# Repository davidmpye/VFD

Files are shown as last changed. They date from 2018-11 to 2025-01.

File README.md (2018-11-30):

This repository contains a design for an IV-11 based Vacuum Fluorescent Display (VFD) display unit.

Key points of the design:

* Support for 8 tubes (can install only 6 if you want the traditional 2-2-2 clock display)
* Can daisy chain boards to make longer displays
* Wifi capable (MQTT etc? - firmware doesn't yet enable this)
* Runs off a 5V 2A supply (USB B socket)
* Four buttons for setting time/other functions

Parts count/prices kept down by using 'generic' ebay modules to provide:

* DS3231 Real Time Clock (battery backed)
* Boost converter module to provide the ~25VDC to power the VFD
* Buck converter module to provide 1.5v to heat the cathodes
* Wemos D1 Mini board to provide the brains
* 5mm encapsulated addressable RGB LEDs to provide the colour effects.

Finished clock

Please see the project wiki for more details.

https://github.com/davidmpye/VFD/wiki

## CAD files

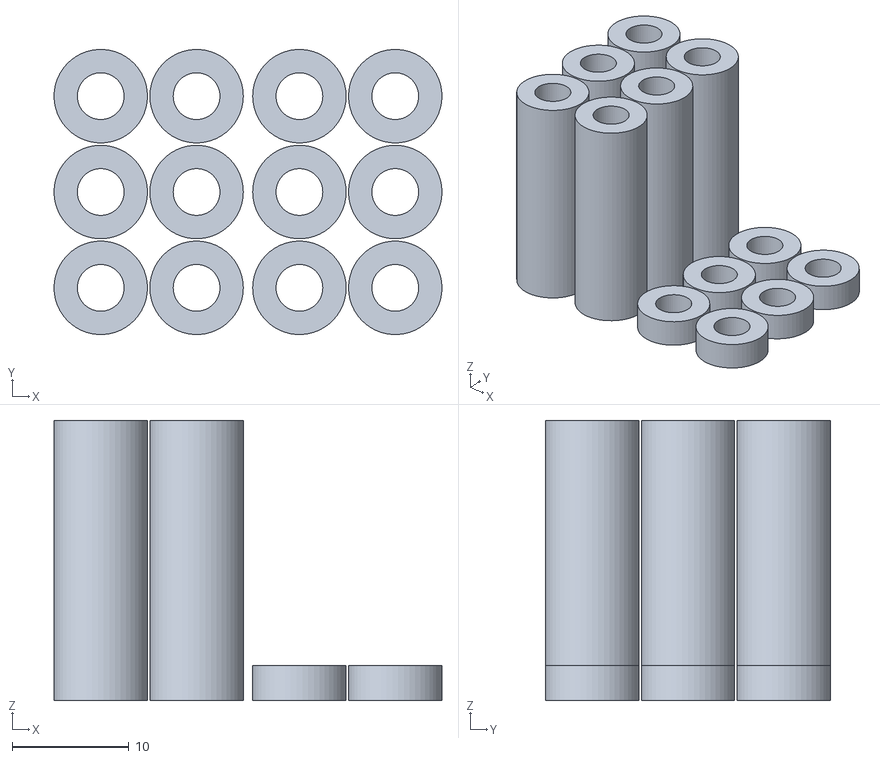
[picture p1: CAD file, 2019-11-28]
IV11/Spacers.stl
33.2 x 24.4 x 24.0

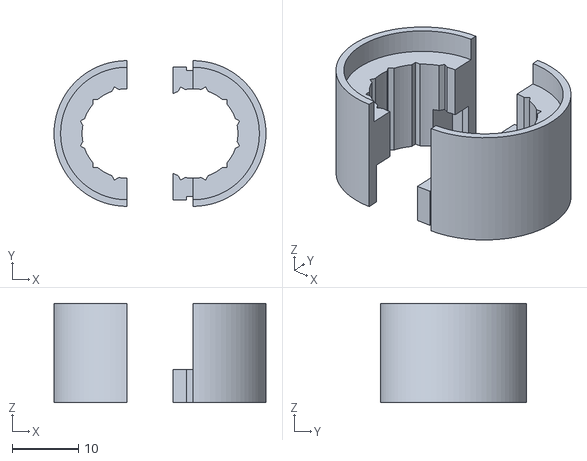
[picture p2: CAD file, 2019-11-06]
IV11/IV11Base.stl
32.0 x 22.0 x 15.0

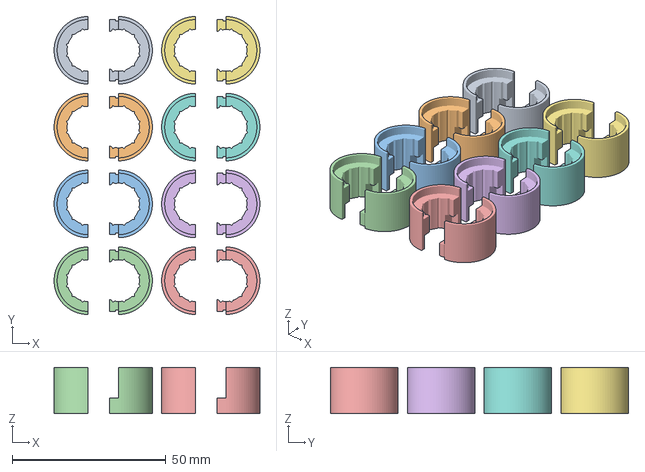
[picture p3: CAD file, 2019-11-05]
IV11/IV11basesx8.3mf
67.0 x 97.0 x 15.0 mm

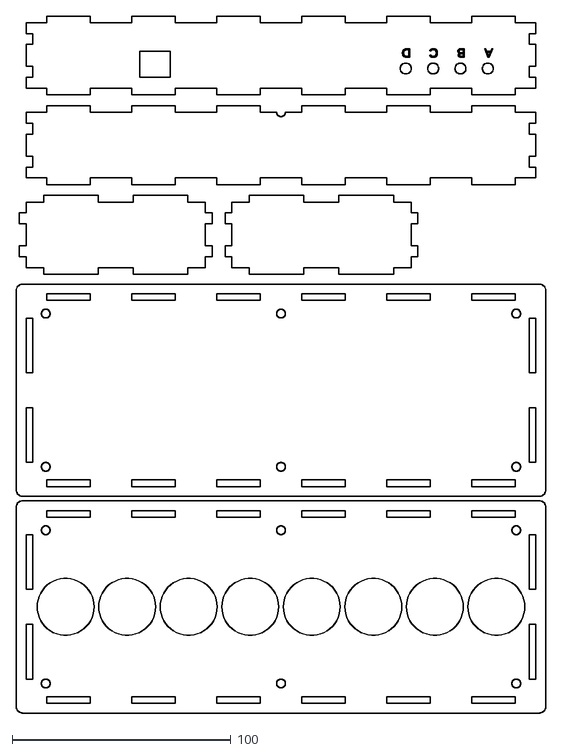
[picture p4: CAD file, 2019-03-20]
IV11/clock_case.dxf
242.0 x 318.5

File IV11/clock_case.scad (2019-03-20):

$fn=50;

material_thickness = 3; //in mm

outer_x = 225 + 2  + material_thickness * 4;
outer_y = 80 + 2  + material_thickness * 4;
outer_z = 30 + 2*material_thickness; //30 inside


x_edge_notches = 6;		//Number of notches along the X side of the box
x_edge_notch_len = 20;

y_edge_notches = 2;		//Number of notches along the Y side of box
y_edge_notch_len = 25;

z_edge_notches = 2;    
z_edge_notch_len = 5;

z_edge_gap_between_notches = ( ((outer_z-2*material_thickness) - (z_edge_notch_len * z_edge_notches)) / z_edge_notches);
//space INSIDE box is as follows:

//X is outer_x  minus 4x material thickness
//Y is outer_y minux 4xmaterial thickness
//Z is outer_z minus 2x material_thickness



long_edge_gap_between_notches = (outer_y - (material_thickness*4) -  (y_edge_notch_len * y_edge_notches)) / y_edge_notches  ;
short_edge_gap_between_notches = (outer_x - (material_thickness*2) -  (x_edge_notch_len * x_edge_notches)) / x_edge_notches;


module top_face() {
radius = 3;
   difference() {
		//square([outer_x,outer_y]);
		hull() {

    		translate([(radius/2), (radius/2), 0])
    		circle(r=radius);

   		translate([(outer_x)-(radius/2), (radius/2), 0])
    		circle(r=radius);

    		translate([(radius/2), (outer_y)-(radius/2), 0])
    		circle(r=radius);

   		 translate([(outer_x)-(radius/2), (outer_y)-(radius/2), 0])
   		 circle(r=radius);		
		}


		for (a=[0:y_edge_notches-1]) {
			translate([material_thickness,  material_thickness*2 + ((long_edge_gap_between_notches * a ) + (a * y_edge_notch_len) +  (0.5 * long_edge_gap_between_notches)) ,0]  ) square([material_thickness,y_edge_notch_len]);
   	}
	
		for (a=[0:y_edge_notches-1]) {
			translate([outer_x - ( material_thickness*2),  (2*material_thickness + (long_edge_gap_between_notches * a ) + (a * y_edge_notch_len) +  (0.5 * long_edge_gap_between_notches)) ,0]  ) square([material_thickness,y_edge_notch_len]);
		}

	for (a=[0:x_edge_notches-1]) {
			
translate([material_thickness + x_edge_notch_len + 0.5*short_edge_gap_between_notches + x_edge_notch_len*a + a*short_edge_gap_between_notches,material_thickness,0]) rotate([0,0,90]) square([material_thickness, x_edge_notch_len]);
		}

	for (a=[0:x_edge_notches-1]) {
			
translate([material_thickness + x_edge_notch_len + 0.5*short_edge_gap_between_notches + x_edge_notch_len*a + a*short_edge_gap_between_notches,outer_y - (material_thickness*2),0]) rotate([0,0,90]) square([material_thickness, x_edge_notch_len]);
		}

	}
}

module long_side_face() {
	union() {
		square([outer_y-(material_thickness*4), outer_z - (material_thickness*2)]);
		//lugs for the long edge
		for (a=[0:y_edge_notches-1]) {
			translate([((long_edge_gap_between_notches * a ) + (a * y_edge_notch_len) +  (0.5 * long_edge_gap_between_notches)),-material_thickness,0]) square([y_edge_notch_len, outer_z]);
		}

			}
		for (a=[0:z_edge_notches - 1 ]) {
			translate([-material_thickness,(0.5 * z_edge_gap_between_notches) + (z_edge_notch_len * a) + (a*z_edge_gap_between_notches),0]) square([material_thickness, z_edge_notch_len]);

			translate([outer_y - 4*material_thickness,(0.5 * z_edge_gap_between_notches) + (z_edge_notch_len * a) + (a*z_edge_gap_between_notches),0]) square([material_thickness, z_edge_notch_len]);
		}



}

module short_side_face() {
	difference() {
		union() {
			square([outer_x - (2*material_thickness), outer_z-(2*material_thickness)]);
			//lugs
			for (a=[0:x_edge_notches-1]) {
				translate([0.5*short_edge_gap_between_notches + x_edge_notch_len*a + a*short_edge_gap_between_notches,-material_thickness,0]) square([x_edge_notch_len,outer_z]);
			}
		}

		//Z notches
		for (a=[0:z_edge_notches - 1 ]) {
			translate([0,(0.5 * z_edge_gap_between_notches) + (z_edge_notch_len * a) + (a*z_edge_gap_between_notches),0]) square([material_thickness, z_edge_notch_len]);

			translate([outer_x - 3*material_thickness,(0.5 * z_edge_gap_between_notches) + (z_edge_notch_len * a) + (a*z_edge_gap_between_notches),0]) square([material_thickness, z_edge_notch_len]);
		}
	}
}

vfd_tube_dia = 24+2;

difference() {
	top_face();
    translate([2*material_thickness + 1, 2*material_thickness + 1, 0]) {
        for (a=[0:7]) {
            //VFD holes
            translate([14.0625 + (28.125 * a), 40,0]) circle(d=vfd_tube_dia);     
        }
        //the 6 M4 mounting holes.
        //the 6 M4 mounting holes.
        translate([5,5,0]) circle(d=4);
        translate([5,75,0]) circle(d=4);
        translate([225 - 5,5,0]) circle(d=4);
        translate([225 - 5,75,0]) circle(d=4);
        translate([225/2,5,0]) circle(d=4);
        translate([225/2,75,0]) circle(d=4);
    
       //LDR hole if wanted top mounted one
     //  translate([225/2 + 12,5,0]) circle(d=5);
         
       }    
}



translate([0,outer_y + 5,0]) difference() {
	top_face();
      translate([2*material_thickness + 1, 2*material_thickness + 1, 0]) {
       //the 6 M4 mounting holes.
        translate([5,5,0]) circle(d=4);
        translate([5,75,0]) circle(d=4);
        translate([225 - 5,5,0]) circle(d=4);
        translate([225 - 5,75,0]) circle(d=4);
        translate([225/2,5,0]) circle(d=4);
        translate([225/2,75,0]) circle(d=4);
      }


}


translate([material_thickness,outer_y*2 + 5 + material_thickness*2 + 3,0]) rotate(0,0,0) difference() {
    long_side_face();        
}

translate([material_thickness + outer_y,outer_y*2 + 5 + material_thickness*2 + 3,0]) rotate(0,0,0) long_side_face();

translate([material_thickness, outer_y*2 + outer_z + 10 + material_thickness*2 + 3 ,0]) difference() {
    short_side_face() ;
    //This takes a small nick out of the front face to make it easier to mount the LDR forward facing into room.
    translate([outer_x/2 - material_thickness, outer_z - material_thickness - 3, 0]) circle(r=2);
}
    

translate([material_thickness, outer_y*2 + outer_z *2 + 15 + material_thickness*2 + 3 ,0]) difference() {
short_side_face();
      translate([2*material_thickness + 1, 2*material_thickness, -1]) {
       
       //the four switch holes.
       //m4
       translate([222.5 - 18.5 - 12.5*0 ,3, 0]) circle(d=5);
       translate([222.5 - 18.5 - 12.5*1 ,3, 0]) circle(d=5);
       translate([222.5 - 18.5 - 12.5*2 ,3, 0]) circle(d=5);
       translate([222.5 - 18.5 - 12.5*3 ,3 ,0]) circle(d=5);
          
       //Labels for the switch button holes   
       translate([222.5 - 18.5 - 12.5*0 +2.25 ,12, 0]) rotate([0,0,180]) text(size=4, text="A");
       translate([222.5 - 18.5 - 12.5*1 +2.25 ,12, 0]) rotate([0,0,180]) text(size=4, text="B");
       translate([222.5 - 18.5 - 12.5*2 +2.25 ,12, 0]) rotate([0,0,180]) text(size=4, text="C");
       translate([222.5 - 18.5 - 12.5*3 +2.25 ,12, 0]) rotate([0,0,180]) text(size=4, text="D");
      
      //The USB power connector.
      //14wide, 12 high.
      translate([45,-1,0]) square([14,12]);   
          
          
      }
      
}

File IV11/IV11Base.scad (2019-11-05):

//Uses Nophead's polyhole.
module polyhole(h, d) {
    n = max(round(2 * d),3);
    rotate([0,0,180])
        cylinder(h = h, r = (d / 2) / cos (180 / n), $fn = n);
}

$fn=80;
total_height = 15;
neopixel_width = 8;
tube_dia = 20;
wall_thickness = 1;
base_thickness = 12;
num_pins = 12;
pin_diameter = 12;
pin_hole_dia = 1.8;

//Half with lugs.
union() {
difference() {
  cylinder(r=(tube_dia/2) + wall_thickness, h = total_height); 
  translate([0,0,base_thickness]) cylinder(r=tube_dia/2, h = 100);  
  translate([-0.01,0,0]) cylinder(d=13.5, h=100); 
    
  //translate([-neopixel_width/2,-neopixel_width/2,-0.1]) cube([neopixel_width, neopixel_width,100]);
  for (i=[0:num_pins-1]) rotate([0,0,(360/num_pins/2) + 360/num_pins * i]) translate([pin_diameter/2,0,-0.1]) polyhole(100, pin_hole_dia);
      
  
  //chop it in half.
 translate([0,-25,0]) cube([50,50,50]);

 translate([-3,-10,0]) cube([5,20,5.4]);
}
# translate([-1,-10,0]) cube([1,0.5,5.4]);
# translate([-1,9.5,0]) cube([1,0.5,5.4]);

}

//Half without lugs!
translate([10,0,0]) rotate([0,0,180]) difference() {
  cylinder(r=(tube_dia/2) + wall_thickness, h = total_height); 
  translate([0,0,base_thickness]) cylinder(r=tube_dia/2, h = 100);  
  translate([-0.01,0,0]) cylinder(d=13.5, h=100); 
    
  //translate([-neopixel_width/2,-neopixel_width/2,-0.1]) cube([neopixel_width, neopixel_width,100]);
  for (i=[0:num_pins-1]) rotate([0,0,(360/num_pins/2) + 360/num_pins * i]) translate([pin_diameter/2,0,-0.1]) polyhole(100, pin_hole_dia);
      
    difference() {
        translate([0,-25,0]) cube([50,50,50]);
        translate([-2,-10,0]) cube([5,20,5]);
        
        
    }
        # translate([0,-10,0]) cube([1,0.5,5]);
        # translate([0,9.5,0]) cube([1,0.5,5]);


}

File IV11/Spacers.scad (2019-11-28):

$fn = 50;

module spacer(height) {
difference() {
    cylinder(d=8, h=height);
    translate([0,0,-0.1]) cylinder(d=4, h=height+1);


}}



for (i = [0:2]) {
    for (j = [0:1]) {
    translate([j*8.2,  i*8.2, 0]) spacer(24);
}
}


translate([17,0,0]) for (i = [0:2]) {
    for (j = [0:1]) {
    translate([j*8.2,  i*8.2, 0]) spacer(3);
}
}

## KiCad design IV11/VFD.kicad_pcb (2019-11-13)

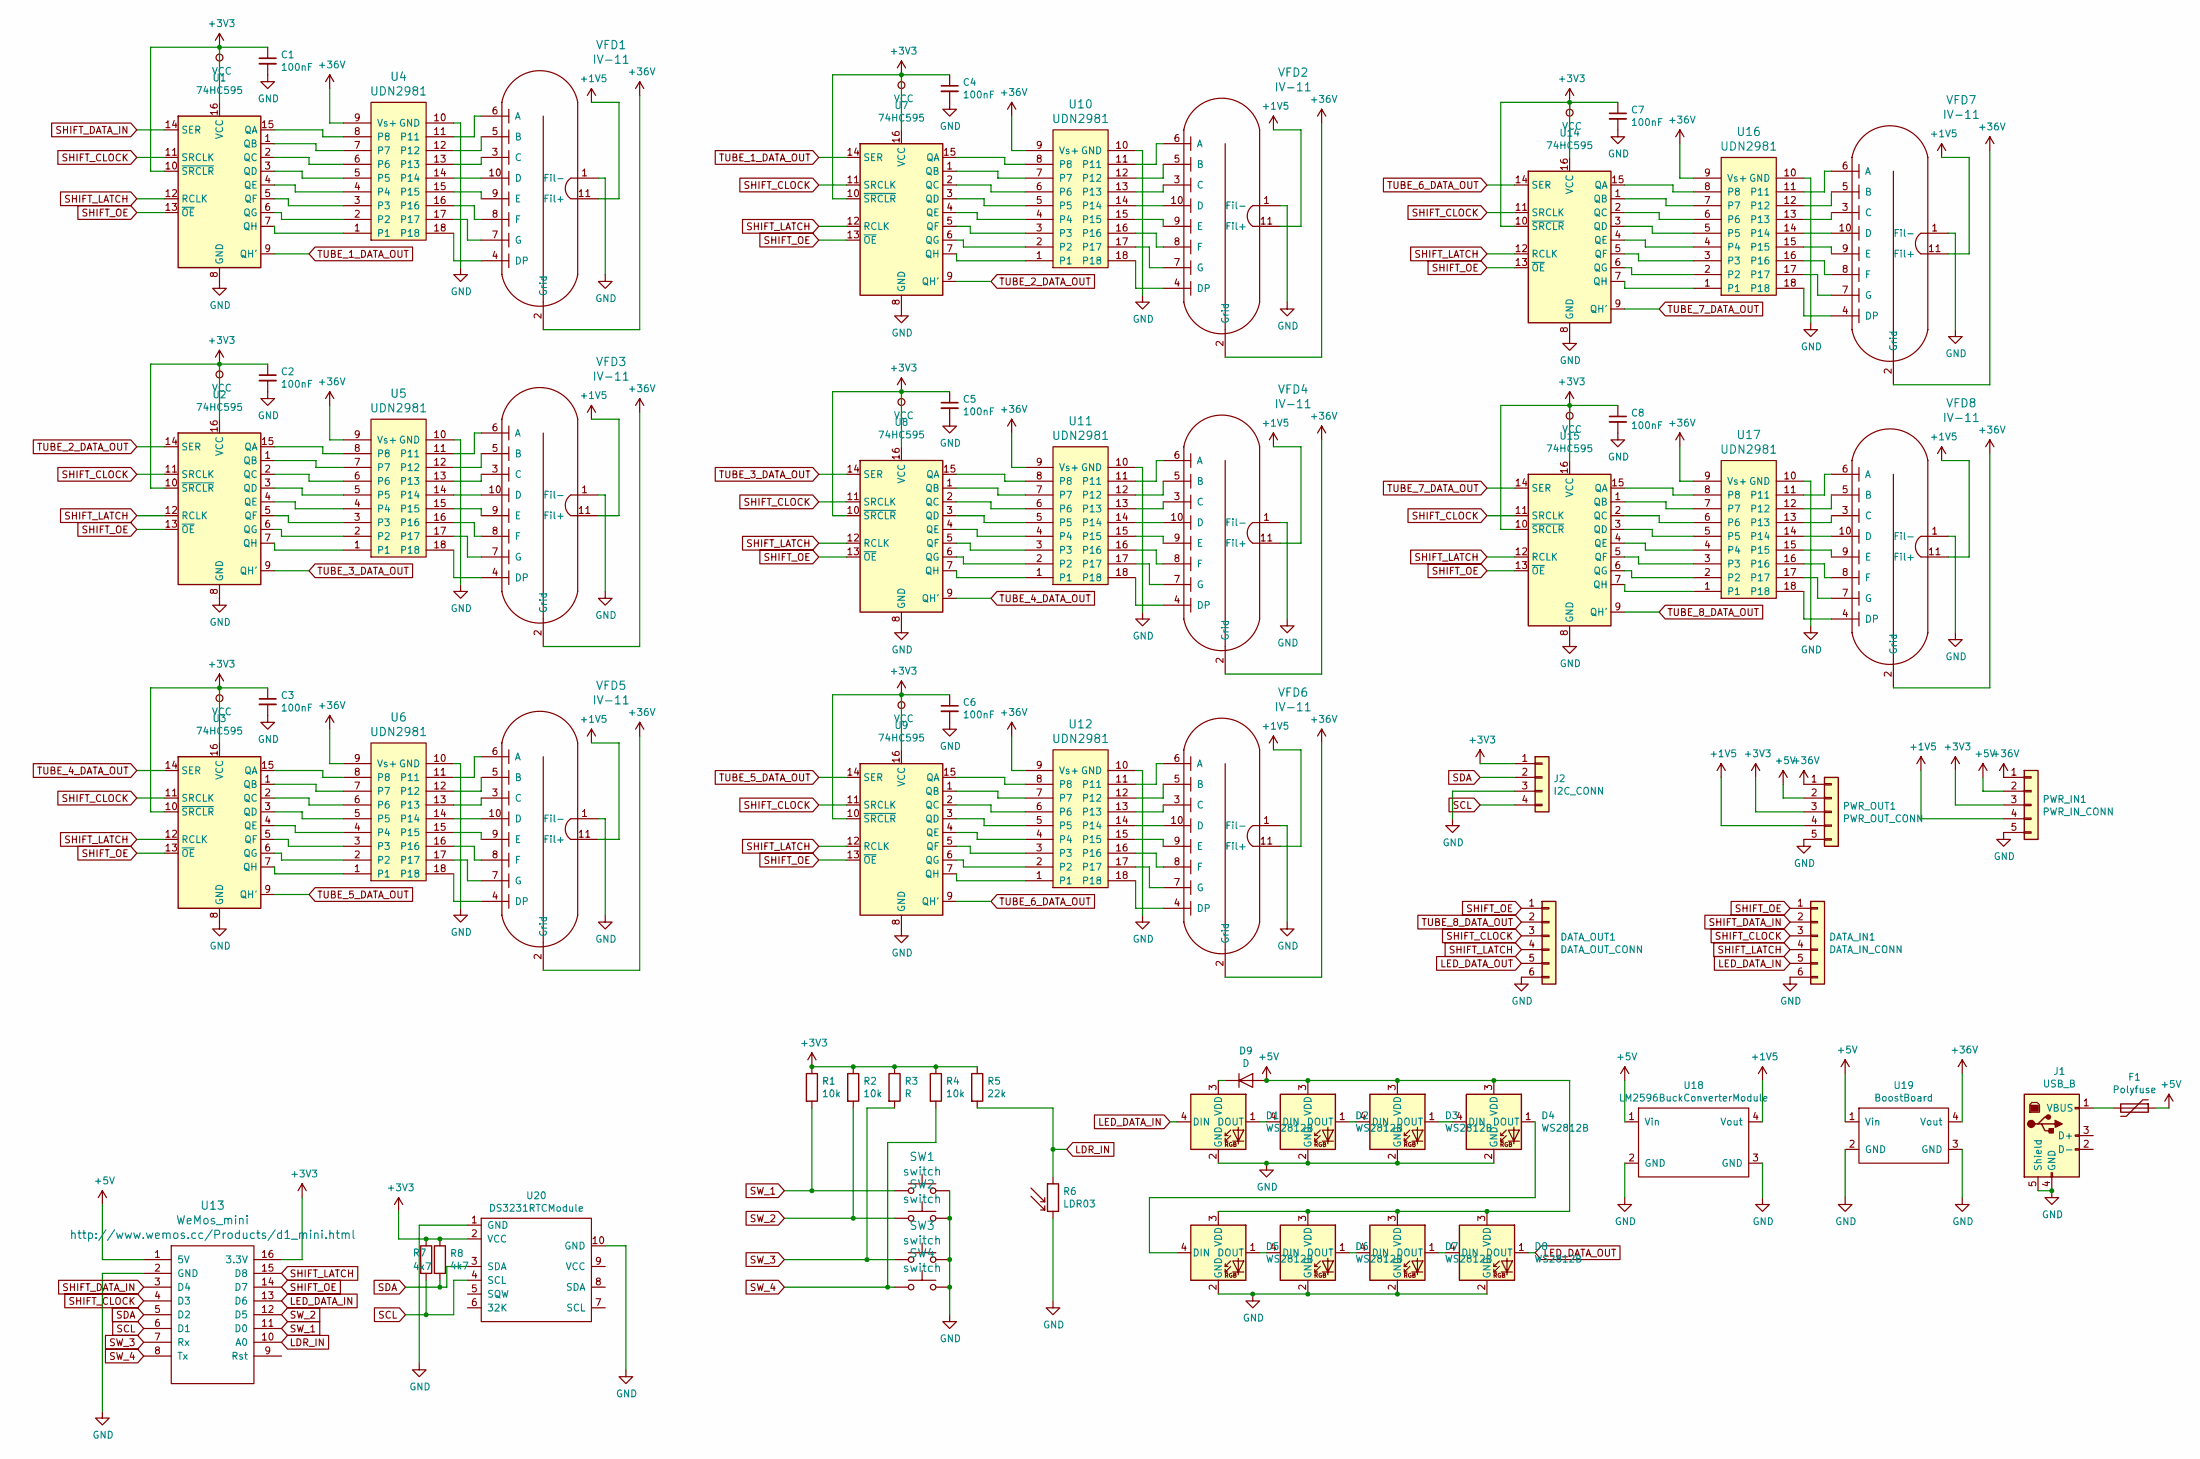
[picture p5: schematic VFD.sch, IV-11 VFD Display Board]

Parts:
C1, C2, C3, C4, C5, C6, C7, C8: 100nF; C_Disc_D7.0mm_W2.5mm_P5.00mm
D1, D2, D3, D4, D5, D6, D7, D8: WS2812B; LED_D5.0mm-4-Wide
D9: D; D_DO-35_SOD27_P7.62mm_Horizontal
DATA_IN1: DATA_IN_CONN; PinSocket_1x06_P2.54mm_Horizontal
DATA_OUT1: DATA_OUT_CONN; PinHeader_1x06_P2.54mm_Horizontal
F1: Polyfuse; R_Axial_DIN0309_L9.0mm_D3.2mm_P15.24mm_Horizontal
J1: USB_B; USB_B_OST_USB-B1HSxx_Horizontal
J2: I2C_CONN; PinHeader_1x04_P2.54mm_Horizontal
PWR_IN1: PWR_IN_CONN; PinSocket_1x05_P2.54mm_Horizontal
PWR_OUT1: PWR_OUT_CONN; PinHeader_1x05_P2.54mm_Horizontal
R1, R2, R4: 10k; R_Axial_DIN0411_L9.9mm_D3.6mm_P12.70mm_Horizontal
R3: R; R_Axial_DIN0411_L9.9mm_D3.6mm_P12.70mm_Horizontal
R5: 22k; R_Axial_DIN0411_L9.9mm_D3.6mm_P12.70mm_Horizontal
R6: LDR03; R_LDR_10x8.5mm_P7.6mm_Vertical
R7, R8: 4k7; R_Axial_DIN0411_L9.9mm_D3.6mm_P12.70mm_Horizontal
SW1, SW2, SW3, SW4: switch; SW_Tactile_SKHH_Angled
U1, U2, U3, U7, U8, U9, U14, U15: 74HC595; DIP-16_W7.62mm_Socket_LongPads
U4, U5, U6, U10, U11, U12, U16, U17: UDN2981; DIP-18_W7.62mm_Socket_LongPads
U13: WeMos_mini; D1_mini_board
U18: LM2596BuckConverterModule
U19: BoostBoard; MT3608BoostConverterModule
U20: DS3231RTCModule; DS3121RTCModule
VFD1, VFD2, VFD3, VFD4, VFD5, VFD6, VFD7, VFD8: IV-11

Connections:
+1V5: PWR_IN1.4, PWR_OUT1.4, U18.4 (Vout), VFD1.11 (Fil+), VFD2.11 (Fil+), VFD3.11 (Fil+), VFD4.11 (Fil+), VFD5.11 (Fil+), VFD6.11 (Fil+), VFD7.11 (Fil+), VFD8.11 (Fil+)
+3V3: C1.1, C2.1, C3.1, C4.1, C5.1, C6.1, C7.1, C8.1, J2.1, PWR_IN1.3, PWR_OUT1.3, R1.1, R2.1, R3.1, R4.1, R5.1, R7.1, R8.1, U1.10 (~SRCLR), U1.16 (VCC), U2.10 (~SRCLR), U2.16 (VCC), U3.10 (~SRCLR), U3.16 (VCC), U7.10 (~SRCLR), U7.16 (VCC), U8.10 (~SRCLR), U8.16 (VCC), U9.10 (~SRCLR), U9.16 (VCC), U13.16 (3.3V), U14.10 (~SRCLR), U14.16 (VCC), U15.10 (~SRCLR), U15.16 (VCC), U20.2 (VCC)
+5V: D2.3 (VDD), D3.3 (VDD), D4.3 (VDD), D5.3 (VDD), D6.3 (VDD), D7.3 (VDD), D8.3 (VDD), D9.2 (A), F1.1, PWR_IN1.2, PWR_OUT1.2, U13.1 (5V), U18.1 (Vin), U19.1 (Vin)
+36V: PWR_IN1.1, PWR_OUT1.1, U4.9 (Vs+), U5.9 (Vs+), U6.9 (Vs+), U10.9 (Vs+), U11.9 (Vs+), U12.9 (Vs+), U16.9 (Vs+), U17.9 (Vs+), U19.4 (Vout), VFD1.2 (Grid), VFD2.2 (Grid), VFD3.2 (Grid), VFD4.2 (Grid), VFD5.2 (Grid), VFD6.2 (Grid), VFD7.2 (Grid), VFD8.2 (Grid)
GND: C1.2, C2.2, C3.2, C4.2, C5.2, C6.2, C7.2, C8.2, D1.2 (GND), D2.2 (GND), D3.2 (GND), D4.2 (GND), D5.2 (GND), D6.2 (GND), D7.2 (GND), D8.2 (GND), DATA_IN1.6, DATA_OUT1.6, J1.4 (GND), J1.5 (Shield), J2.3, PWR_IN1.5, PWR_OUT1.5, R6.2, SW1.2, SW2.2, SW3.2, SW4.2, U1.8 (GND), U2.8 (GND), U3.8 (GND), U4.10 (GND), U5.10 (GND), U6.10 (GND), U7.8 (GND), U8.8 (GND), U9.8 (GND), U10.10 (GND), U11.10 (GND), U12.10 (GND), U13.2 (GND), U14.8 (GND), U15.8 (GND), U16.10 (GND), U17.10 (GND), U18.2 (GND), U18.3 (GND), U19.2 (GND), U19.3 (GND), U20.1 (GND), U20.10 (GND), VFD1.1 (Fil-), VFD2.1 (Fil-), VFD3.1 (Fil-), VFD4.1 (Fil-), VFD5.1 (Fil-), VFD6.1 (Fil-), VFD7.1 (Fil-), VFD8.1 (Fil-)
LDR_IN: R5.2, R6.1, U13.10 (A0)
LED_DATA_IN: D1.4 (DIN), DATA_IN1.5, U13.13 (D6)
LED_DATA_OUT: D8.1 (DOUT), DATA_OUT1.5
unnamed: D1.1 (DOUT), D2.4 (DIN)
unnamed: D1.3 (VDD), D9.1 (K)
unnamed: D2.1 (DOUT), D3.4 (DIN)
unnamed: D3.1 (DOUT), D4.4 (DIN)
unnamed: D4.1 (DOUT), D5.4 (DIN)
unnamed: D5.1 (DOUT), D6.4 (DIN)
unnamed: D6.1 (DOUT), D7.4 (DIN)
unnamed: D7.1 (DOUT), D8.4 (DIN)
unnamed: F1.2, J1.1 (VBUS)
unnamed: U1.1 (QB), U4.7
unnamed: U1.2 (QC), U4.6
unnamed: U1.3 (QD), U4.5
unnamed: U1.4 (QE), U4.4
unnamed: U1.5 (QF), U4.3
unnamed: U1.6 (QG), U4.2
unnamed: U1.7 (QH), U4.1
unnamed: U1.15 (QA), U4.8
unnamed: U2.1 (QB), U5.7
unnamed: U2.2 (QC), U5.6
unnamed: U2.3 (QD), U5.5
unnamed: U2.4 (QE), U5.4
unnamed: U2.5 (QF), U5.3
unnamed: U2.6 (QG), U5.2
unnamed: U2.7 (QH), U5.1
unnamed: U2.15 (QA), U5.8
unnamed: U3.1 (QB), U6.7
unnamed: U3.2 (QC), U6.6
unnamed: U3.3 (QD), U6.5
unnamed: U3.4 (QE), U6.4
unnamed: U3.5 (QF), U6.3
unnamed: U3.6 (QG), U6.2
unnamed: U3.7 (QH), U6.1
unnamed: U3.15 (QA), U6.8
unnamed: U4.11, VFD1.6 (A)
unnamed: U4.12, VFD1.5 (B)
unnamed: U4.13, VFD1.3 (C)
unnamed: U4.14, VFD1.10 (D)
unnamed: U4.15, VFD1.9 (E)
unnamed: U4.16, VFD1.8 (F)
unnamed: U4.17, VFD1.7 (G)
unnamed: U4.18, VFD1.4 (DP)
unnamed: U5.11, VFD3.6 (A)
unnamed: U5.12, VFD3.5 (B)
unnamed: U5.13, VFD3.3 (C)
unnamed: U5.14, VFD3.10 (D)
unnamed: U5.15, VFD3.9 (E)
unnamed: U5.16, VFD3.8 (F)
unnamed: U5.17, VFD3.7 (G)
unnamed: U5.18, VFD3.4 (DP)
unnamed: U6.11, VFD5.6 (A)
unnamed: U6.12, VFD5.5 (B)
unnamed: U6.13, VFD5.3 (C)
unnamed: U6.14, VFD5.10 (D)
unnamed: U6.15, VFD5.9 (E)
unnamed: U6.16, VFD5.8 (F)
unnamed: U6.17, VFD5.7 (G)
unnamed: U6.18, VFD5.4 (DP)
unnamed: U7.7 (QH), U10.1
unnamed: U7.6 (QG), U10.2
unnamed: U7.5 (QF), U10.3
unnamed: U7.4 (QE), U10.4
unnamed: U7.3 (QD), U10.5
unnamed: U7.2 (QC), U10.6
unnamed: U7.1 (QB), U10.7
unnamed: U7.15 (QA), U10.8
unnamed: U10.11, VFD2.6 (A)
unnamed: U10.12, VFD2.5 (B)
unnamed: U10.13, VFD2.3 (C)
unnamed: U10.14, VFD2.10 (D)
unnamed: U10.15, VFD2.9 (E)
unnamed: U10.16, VFD2.8 (F)
unnamed: U10.17, VFD2.7 (G)
unnamed: U10.18, VFD2.4 (DP)
unnamed: U8.7 (QH), U11.1
unnamed: U8.6 (QG), U11.2
unnamed: U8.5 (QF), U11.3
unnamed: U8.4 (QE), U11.4
unnamed: U8.3 (QD), U11.5
unnamed: U8.2 (QC), U11.6
unnamed: U8.1 (QB), U11.7
unnamed: U8.15 (QA), U11.8
unnamed: U11.11, VFD4.6 (A)
unnamed: U11.12, VFD4.5 (B)
unnamed: U11.13, VFD4.3 (C)
unnamed: U11.14, VFD4.10 (D)
unnamed: U11.15, VFD4.9 (E)
unnamed: U11.16, VFD4.8 (F)
unnamed: U11.17, VFD4.7 (G)
unnamed: U11.18, VFD4.4 (DP)
unnamed: U9.7 (QH), U12.1
unnamed: U9.6 (QG), U12.2
unnamed: U9.5 (QF), U12.3
unnamed: U9.4 (QE), U12.4
unnamed: U9.3 (QD), U12.5
unnamed: U9.2 (QC), U12.6
unnamed: U9.1 (QB), U12.7
unnamed: U9.15 (QA), U12.8
unnamed: U12.11, VFD6.6 (A)
unnamed: U12.12, VFD6.5 (B)
unnamed: U12.13, VFD6.3 (C)
unnamed: U12.14, VFD6.10 (D)
unnamed: U12.15, VFD6.9 (E)
unnamed: U12.16, VFD6.8 (F)
unnamed: U12.17, VFD6.7 (G)
unnamed: U12.18, VFD6.4 (DP)
unnamed: U14.1 (QB), U16.7
unnamed: U14.2 (QC), U16.6
unnamed: U14.3 (QD), U16.5
unnamed: U14.4 (QE), U16.4
unnamed: U14.5 (QF), U16.3
unnamed: U14.6 (QG), U16.2
unnamed: U14.7 (QH), U16.1
unnamed: U14.15 (QA), U16.8
unnamed: U15.1 (QB), U17.7
unnamed: U15.2 (QC), U17.6
unnamed: U15.3 (QD), U17.5
unnamed: U15.4 (QE), U17.4
unnamed: U15.5 (QF), U17.3
unnamed: U15.6 (QG), U17.2
unnamed: U15.7 (QH), U17.1
unnamed: U15.15 (QA), U17.8
unnamed: U16.11, VFD7.6 (A)
unnamed: U16.12, VFD7.5 (B)
unnamed: U16.13, VFD7.3 (C)
unnamed: U16.14, VFD7.10 (D)
unnamed: U16.15, VFD7.9 (E)
unnamed: U16.16, VFD7.8 (F)
unnamed: U16.17, VFD7.7 (G)
unnamed: U16.18, VFD7.4 (DP)
unnamed: U17.11, VFD8.6 (A)
unnamed: U17.12, VFD8.5 (B)
unnamed: U17.13, VFD8.3 (C)
unnamed: U17.14, VFD8.10 (D)
unnamed: U17.15, VFD8.9 (E)
unnamed: U17.16, VFD8.8 (F)
unnamed: U17.17, VFD8.7 (G)
unnamed: U17.18, VFD8.4 (DP)
SCL: J2.4, R7.2, U13.6 (D1), U20.4 (SCL)
SDA: J2.2, R8.2, U13.5 (D2), U20.3 (SDA)
SHIFT_CLOCK: DATA_IN1.3, DATA_OUT1.3, U1.11 (SRCLK), U2.11 (SRCLK), U3.11 (SRCLK), U7.11 (SRCLK), U8.11 (SRCLK), U9.11 (SRCLK), U13.4 (D3), U14.11 (SRCLK), U15.11 (SRCLK)
SHIFT_DATA_IN: DATA_IN1.2, U1.14 (SER), U13.3 (D4)
SHIFT_LATCH: DATA_IN1.4, DATA_OUT1.4, U1.12 (RCLK), U2.12 (RCLK), U3.12 (RCLK), U7.12 (RCLK), U8.12 (RCLK), U9.12 (RCLK), U13.15 (D8), U14.12 (RCLK), U15.12 (RCLK)
SHIFT_OE: DATA_IN1.1, DATA_OUT1.1, U1.13 (~OE), U2.13 (~OE), U3.13 (~OE), U7.13 (~OE), U8.13 (~OE), U9.13 (~OE), U13.14 (D7), U14.13 (~OE), U15.13 (~OE)
SW_1: R1.2, SW1.1, U13.11 (D0)
SW_2: R2.2, SW2.1, U13.12 (D5)
SW_3: R3.2, SW3.1, U13.7 (Rx)
SW_4: R4.2, SW4.1, U13.8 (Tx)
TUBE_1_DATA_OUT: U1.9 (QH'), U7.14 (SER)
TUBE_2_DATA_OUT: U2.14 (SER), U7.9 (QH')
TUBE_3_DATA_OUT: U2.9 (QH'), U8.14 (SER)
TUBE_4_DATA_OUT: U3.14 (SER), U8.9 (QH')
TUBE_5_DATA_OUT: U3.9 (QH'), U9.14 (SER)
TUBE_6_DATA_OUT: U9.9 (QH'), U14.14 (SER)
TUBE_7_DATA_OUT: U14.9 (QH'), U15.14 (SER)
TUBE_8_DATA_OUT: DATA_OUT1.2, U15.9 (QH')

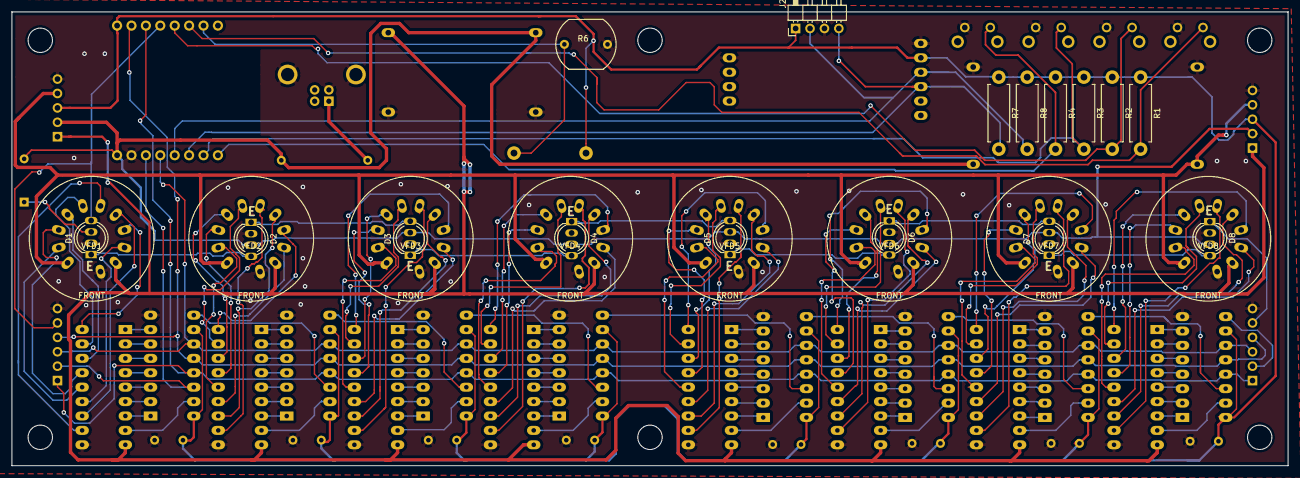
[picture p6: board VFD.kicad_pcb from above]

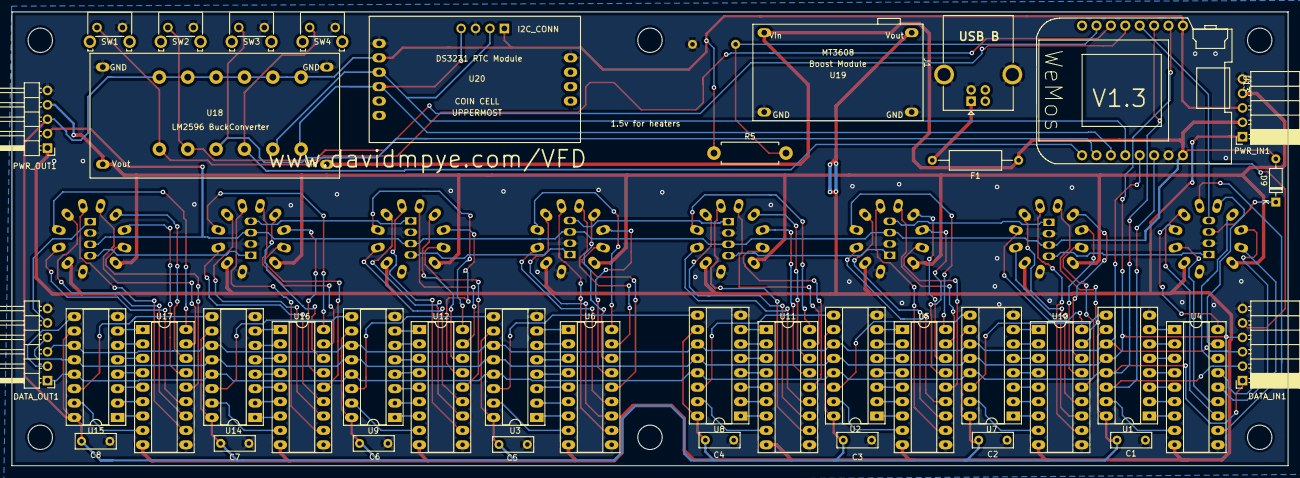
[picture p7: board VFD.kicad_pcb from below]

Board: 2 copper layers, 225.0 x 80.0 mm, 64 parts (40 on the bottom side), 163 nets.

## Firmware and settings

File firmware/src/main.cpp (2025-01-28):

/*
    VFD clock firmware (c) 2018 David Pye <davidmpye@gmail.com>

    http://www.davidmpye.com/VFD

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
    You should have received a copy of the GNU General Public License
    along with this program.  If not, see <https://www.gnu.org/licenses/>.
*/
#include "Clock.h"
#include <coredecls.h> 

Clock c;

void setNTPtime() {
  c.checkNTP();
}

void setup() {
  settimeofday_cb(setNTPtime);
  c.begin();
}


void loop() {
  c.loop();
  yield();
}

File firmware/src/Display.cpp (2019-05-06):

/*
    VFD clock firmware (c) 2018 David Pye <davidmpye@gmail.com>

    http://www.davidmpye.com/VFD

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
    You should have received a copy of the GNU General Public License
    along with this program.  If not, see <https://www.gnu.org/licenses/>.
*/

#include "Display.h"

extern "C" {
  //We use this to turn off the brightness PWM while using FastLED
  void stopWaveform(int);
}

Display::Display() {
}

Display::~Display() {

}

void Display::begin() {
  pinMode(LATCH_PIN, OUTPUT);
  pinMode(CLOCK_PIN, OUTPUT);
  pinMode(DATA_PIN, OUTPUT);
  pinMode(OE_PIN, OUTPUT);
  pinMode(LED_PIN, OUTPUT);

  //Setting the PWM frequency to ~50Hz makes the inductor in the boost converter hum far less.
  analogWriteFreq(50);
  //PWM range 0-255.
  analogWriteRange(256);

  //Set all tubes to OFF.
  memset(_displayData, 0x00, NUM_TUBES);
  //Set up the LEDs
  LEDS.addLeds<APA106,LED_PIN,RGB>(leds,NUM_LEDS).setCorrection(TypicalLEDStrip);;

  //Full brightness.
  brightness = 255;

  ledsOff = false;

  update();
}

void Display::displayTime(DateTime t) {
  clear();
  if (configManager->data.disp_timeformat == EPOCH_MODE) {
       time_t epochtime = t.unixtime(); //!
       for (int i=0; i<8; i++) {
         setTubeNumber(NUM_TUBES - 1 - i, (epochtime>>(4*i)) & 0x0F);
       }
  }
  else {
     //Normal modes...
     if (configManager->data.disp_timeformat == AMPM_MODE && t.hour() > 12) {
       //If it's PM, dont display a 0 as first digit.
       if ((t.hour() - 12 )/10 == 0) setTubeByte(0,0x00);
       else setTubeNumber(0,1);
       setTubeDP(0, true);
       setTubeNumber(1, (t.hour()-12)%10);
     }
     else {
       //Display as 24 hour mode.
       setTubeNumber(0,t.hour()/10);
       setTubeNumber(1,t.hour()%10);
     }

     if (NUM_TUBES == 6) {
       //These are the same for either ampm/24 hr mode
        setTubeNumber(2, t.minute()/10);
        setTubeNumber(3, t.minute()%10);
        setTubeNumber(4, t.second()/10);
        setTubeNumber(5, t.second()%10);
     }
     else if (NUM_TUBES == 8) {
     //These are the same for either ampm/24 hr mode
      setTubeNumber(3, t.minute()/10);
      setTubeNumber(4, t.minute()%10);
      setTubeNumber(6, t.second()/10);
      setTubeNumber(7, t.second()%10);
    }
   }
   if (NUM_TUBES == 8 && ( configManager->data.disp_timeformat == TWENTYFOURHR_MODE || configManager->data.disp_timeformat == AMPM_MODE)) {
     if (t.second() %2 == 0) {
       byte b = 0x00;
       if (configManager->data.disp_separator == SEP_DASH) {
         b = 0x40;
       }
       else if (configManager->data.disp_separator == SEP_DOUBLE_DASH) {
         b = 0x09;
       }
       setTubeByte(2, b);
       setTubeByte(5, b);
     }
   }
}

void Display::displayDate(DateTime t) {
  clear();
  if (NUM_TUBES == 6) {
    switch (configManager->data.disp_dateformat) {
      case DDMMYY_MODE:
        setTubeNumber(0, t.day()/10);
        setTubeNumber(1, t.day()%10);
        setTubeNumber(2, t.month()/10);
        setTubeNumber(3, t.month()%10);
        break;
      case MMDDYY_MODE:
        setTubeNumber(2, t.day()/10);
        setTubeNumber(3, t.day()%10);
        setTubeNumber(0, t.month()/10);
        setTubeNumber(1, t.month()%10);
      break;
    }
    setTubeNumber(4, (t.year()-2000)/10);
    setTubeNumber(5, (t.year()-2000)%10);
  }
  else if (NUM_TUBES ==8) {
    setTubeByte(2, 0x40);
    setTubeByte(5, 0x40);

    switch (configManager->data.disp_dateformat) {
      case DDMMYY_MODE:
        setTubeNumber(0, t.day()/10);
        setTubeNumber(1, t.day()%10);
        setTubeNumber(3, t.month()/10);
        setTubeNumber(4, t.month()%10);
        break;
      case MMDDYY_MODE:
        setTubeNumber(3, t.day()/10);
        setTubeNumber(4, t.day()%10);
        setTubeNumber(0, t.month()/10);
        setTubeNumber(1, t.month()%10);
      break;
    }
    setTubeNumber(6, (t.year()-2000)/10);
    setTubeNumber(7, (t.year()-2000)%10);
  }
}

void Display::displayInt(int x) {
  displayInt(x, 10);
}

void Display::displayInt(int x, int base) {
  clear();
  for (int i=0; i<NUM_TUBES; ++i) {
      setTubeNumber(NUM_TUBES - 1 -i, x%base);
      x /= base;
      if (x == 0) break;;
  }
}

void Display::scrollMessage(const char *message, int speed) {
  clear();
  size_t length = strlen(message);
  for (int i=0; i<NUM_TUBES+length; i++) {
    for (int t=0; t<NUM_TUBES; t++)
    if (i+1-(NUM_TUBES-t)<0 or i+1-(NUM_TUBES-t)>=length) {
      setTubeByte(t, 0x00);
    }
    else {
      setTubeChar(t, message[i+1-(NUM_TUBES-t)]);
    }
    update();
    delay(1000 / speed);
  }
}

void Display::clear() {
    memset(_displayData, 0x00, NUM_TUBES);
}

void Display::blank() {
  digitalWrite(LATCH_PIN, LOW);
  for (int i=0; i<NUM_TUBES; ++i) {
    shiftOut(DATA_PIN, CLOCK_PIN, MSBFIRST, 0x00);
  }
  digitalWrite(LATCH_PIN, HIGH);
}

void Display::fillLEDData() {
  if (configManager->data.led_backlight == false) {
    for (int i = 0; i < NUM_TUBES; ++i) {
      leds[i] = CRGB::Black;
    }
    return;
  }
  //LEDs are enabled, generate the appropriate colour patterns.
  static uint16_t rainbow_counter = 0;

  switch (configManager->data.led_color_mode) {
    case RAINBOW_MODE:
      rainbow_counter++;
      fill_rainbow(leds, NUM_LEDS, rainbow_counter, 255/NUM_LEDS);
      break;
    case COL_PER_NUM_MODE:
      for (int i = 0; i < NUM_TUBES; ++i) {
        leds[i].setHue(25 * getTubeNumber(i)); //255 / 10 digits - sorry, no extra colors for hex...
      }
      break;
    case COL_BY_TIME_MODE:
      if (NUM_TUBES == 6) {
        uint8_t hue;
        // 24hr based colour regardless of time display mode
        hue  = (getTubeNumber(0) * 10 + getTubeNumber(1)) * 10;
        leds[0].setHue(hue);
        leds[1].setHue(hue);
        hue = (getTubeNumber(2) * 10 + getTubeNumber(3)) * 4;
        leds[2].setHue(hue);
        leds[3].setHue(hue);
        hue = (getTubeNumber(4) * 10 + getTubeNumber(5)) * 4;
        leds[4].setHue(hue);
        leds[5].setHue(hue);
      }
      else if (NUM_TUBES == 8) {
        uint8_t hue;
        hue  = (getTubeNumber(0) * 10 + getTubeNumber(1)) * 10;
        leds[0].setHue(hue);
        leds[1].setHue(hue);
        leds[2] = CRGB::Black;
        hue = (getTubeNumber(3) * 10 + getTubeNumber(4)) * 4;
        leds[3].setHue(hue);
        leds[4].setHue(hue);
        leds[5] = CRGB::Black;
        hue = (getTubeNumber(6) * 10 + getTubeNumber(7)) * 4;
        leds[6].setHue(hue);
        leds[7].setHue(hue);
      }
      break;
    default:
      break;
  }
}

void Display::updateTubes() {
  //Push out the new digit data to the shift registers
  digitalWrite(LATCH_PIN, LOW);
  for (int i=0; i<NUM_TUBES; ++i) {
    shiftOut(DATA_PIN, CLOCK_PIN, MSBFIRST, _displayData[NUM_TUBES - 1 - i]);
  }
  digitalWrite(LATCH_PIN, HIGH);
}
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

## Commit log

2018-06-05 Initial import
    [IV-11-breakout.kicad_pcb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]
2018-06-05 Initial import of 3d printed model for tube base mount
    [IV11Base.scad]
2018-06-07 Further updates!
    [IV-11-breakout.kicad_pcb]
2018-06-07 Tweak silkscreen
    [IV-11-breakout.kicad_pcb]
2018-06-07 Redone without the resistor
    [IV-11-breakout-B.Cu.gbl, IV-11-breakout-B.Mask.gbs, IV-11-breakout-B.SilkS.gbo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]
2018-06-07 Make walls thinner
    [IV11Base.scad]
2018-06-07 Further tweaks to 3d printed base
    [IV11Base.scad]
2018-07-20 Change to make base much thicker to take a 5mm 'encapsulated' neopixel
    [IV11Base.scad]
2018-07-25 Initial push of IV11 modular clock design
    [VFD.kicad_pcb, VFD.sch]
2018-08-02 Make base thicker
    [IV11Base.scad]
2018-08-02 Import kicad cache
2018-08-02 Fix back to front LEDs
2018-08-02 Changes for back to front LED markings
    [VFD.kicad_pcb, VFD.sch]
2018-08-02 UDN2981-THT schematic added
2018-08-02 5mm neopixel schematic added
2018-08-02 Fix footpring mistakes
    [VFD.kicad_pcb, VFD.sch]
2018-08-02 Update footprints to use the 'generic modules'
    [VFD.kicad_pcb, VFD.sch]
2018-08-02 Finish import of new neopixel footprint and associated groundfill changes
    [VFD.kicad_pcb, VFD.sch]
2018-08-07 Redesign tube base so it is in two halves, with interlocking lugs. Reason: Without a splittable removable base, replacing the tubes are almost impossible!
    [IV11Base.scad]
2018-08-07 Updates to use further-spaced LED footprints for the 5mm neopixels to make rework easier!
    [VFD.kicad_pcb, VFD.sch]
2018-08-07 Fixes for not using D0 for the LEDs...
    [VFD.kicad_pcb, VFD.sch]
2018-08-08 Make LED footprint pads slightly narrower (1.3mm) for easier solderingx
    [VFD.kicad_pcb]
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2018-08-08 PCB updates - rerouted track for 3v3 to shift registers and refilled ground planes accordingly
    [VFD.kicad_pcb]
2018-08-08 V1.1 board completed, + gerbers
    [VFD.kicad_pcb, VFD.sch]
2018-08-12 Add Openscad design for the clock case
    [clock_case.scad]
2018-08-12 Slight tweak to hole positions
    [clock_case.scad]
2018-08-24 Adjust cutout holes (again!) for USB hole and the push buttons
    [clock_case.scad]
2018-08-28 Add LDR hole
    [clock_case.scad]
2018-11-01 Fix bug for switches not being connected to ground!
    [VFD.sch]
2018-11-01 Fix problems with switches not being connected to ground
    [VFD.kicad_pcb]
2018-11-01 Update version number (now 1.2). Sigh.
    [VFD.kicad_pcb]
2018-11-02 Import of button handling code - you can now set the time!
2018-11-02 Fix the AMPM display mode bug
    [Display.cpp]
2018-11-02 Tweaks to button layouts
2018-11-02 Now with working button C to select LED colour modes
2018-11-07 Updates to config and button handler - largely reordering functions
2018-11-07 Reordering display driver code and adding comments
2018-11-12 Fix order for setting time->date, and button responsiveness
    [main.cpp]
2018-11-13 Add in test mode with long press on button D to display all segments on all tubes
2018-11-14 Adjust shell to fit together better
    [IV11Base.scad]
2018-11-14 Change LDR resistor val to 22k
    [VFD.sch]
2018-11-17 Remove OSHW logo - unfortunately with the generic modules, we can't meet OSHW requirements
    [VFD.kicad_pcb]
2018-11-17 Final updates to complete PCB revision 1.2 including an I2C breakout connector
    [VFD.kicad_pcb, VFD.sch]
2018-11-17 Re-added gerbers.zip for the 1.2 gerbers
2018-11-17 Add the rest of the kicad project files
2018-11-17 Fix missing } (thanks Jon!)
    [main.cpp]
2018-11-19 Add a long-press of button 3 to display the hex readout from the LDR. Also, recalibrate the LDR readouts for a 22k series resistor
2018-11-21 Multiple fixes to graduated dimming, and allow the LEDs to be turned off at low brightness settings
    [Config.h, Display.cpp, main.cpp]
2018-11-21 Minor tweak to tube position
    [clock_case.scad]
2018-11-21 Fix brightness issue (AGAIN)
    [Display.cpp]
2018-11-23 Make adjustments for front mounted LDR
    [clock_case.scad]
2018-11-23 Add DXF of clock case for non-laser cutter peeps
    [clock_case.dxf]
2018-11-23 Tweaks to LDR hole
    [clock_case.dxf, clock_case.scad]
2018-11-25 Hopefully fix alignment issue with top cover
    [clock_case.dxf, clock_case.scad]
2018-11-25 More antiflicker and anti LED glitching
    [Display.cpp, main.cpp]
2018-11-27 Try increasing the PWM frequency to 400Hz to reduce flicker, and reenable interrupts as it's causing crashes
    [Display.cpp]
2018-11-30 More antiflicker updates, and update to use the latest arduino core from github, which fixes a number of flicker related issues
    [Config.h, Display.cpp, main.cpp]
2018-11-30 Add the FASTLED interrupt disabler again
2018-11-30 Make 3d printed base hole a bit larger for easier fitting
    [IV11Base.scad]
2018-12-05 Final tweaks to case
    [clock_case.scad]
2018-12-05 Spacers if wanted
    [Spacers.scad]
2019-02-21 Stealth and Col By Tikme modes added
    Stealth Mode = no LEDs on
    Col By Time = Colours based on Hours, Minutes and Seconds.
2019-02-21 Stalth Mode fixed
    Stealth Mode fixed so LEDs turn off if they are already on.
    [Display.cpp]
2019-02-23 Changes to synchronise tube numbering to match LED numbering - ie 0 is the leftmost tube
2019-02-23 Fix for merge now tubes are renumbered
    [Display.cpp]
2019-02-23 Another fix needed for tube renumbering
    [Display.cpp]
2019-02-23 Multiple fixes to sort out 6 and 8 tube clock options
    [Config.h, Display.cpp, main.cpp]
2019-02-24 Oops, changed default tube number
2019-02-27 1) Remove NTPClient symlink from /lib, 2) Add NtpClientLib to lib_deps, 3) Add comments, 4) Show connected AP, 5) Fix DP's code ('FF' fault display), 6) Fix my code (unblock clock from starting when 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
    [main.cpp]
2019-02-27 Hello message fixed and fonts annotated
    [Display.cpp]
2019-03-03 Stealth Mode improved in bright conditions
    Stealth Mode changed so LEDs do not update in bright conditions
2019-03-06 1) Beginnings of a simple web server (currently a 'Hello World'), 2) Settings saved to SPIFFS as config.json.
2019-03-06 Remove two IPChar display calls that didn't work
    [main.cpp]
2019-03-06 Fixes to make date display work properly on 8 tubes Fixes to make it possible to set date/time with Iain's new API
    [Display.cpp]
2019-03-20 Add letter labels to the buttons
    [clock_case.dxf, clock_case.scad]
2019-03-20 Fix the bug in 12 hour display mode
    [Display.cpp]
2019-03-20 Further fix to 12 hour mode
    [Display.cpp]
2019-03-21 8 tube firmware upload
2019-03-21 Precompiled firmware binaries for 6 and 8 tube versions
2019-03-21 Fix regression in buttonhandler which broke time and date setting again
    [main.cpp]
2019-04-21 Re-insert the fix for LED flickering, now the ESP8266 Arduino Core has started using NMI for PWM (again). Sigh.x
    [Display.cpp, main.cpp]
2019-04-25 Make holding button 1+2 reset the config settings
    [Clock.cpp]
2019-04-26 Numerous changes to make the configmanager do its' work, and make the webhandler prepopulate button fields for different pages
2019-05-04 Remove the NTPclient libdep as it won't build at the moment! Go back to the 'stage' version of ESP8266 core. Add mDNS support to the code (but not yet the web UI)
    [Clock.cpp]
2019-05-05 Display message to confirm reset
    [Clock.cpp]
2019-05-05 Fix MDNS so it works!
    [Clock.cpp]
2019-05-06 Fix problem with softAP
    [Clock.cpp]
2019-05-06 Add -s for displaying date on 8 tube clocks
2019-11-05 Add barbs for tube bases
    [IV11Base.scad]
2019-11-05 IV11 bases x8 as 3mf file
    [IV11basesx8.3mf]
2019-11-06 Add STL file for tube base for people without OpenSCAD
    [IV11Base.stl]
2019-11-13 Major redesign to use different buck converter, and also up-rate track thickness for power rails
    [VFD.kicad_pcb, VFD.sch]
2019-11-13 Add in room for polyfuse
    [VFD.kicad_pcb, VFD.sch]
2019-11-13 Update thickness of 48VDC tracks x
    [VFD.kicad_pcb, VFD.sch]
2019-11-20 Change design to use 3dprinted spacers
    [Spacers.scad, Spacers.stl]
2019-11-20 Make top spacers a bit thicker
    [Spacers.scad, Spacers.stl]
2019-11-28 Update spacer length
    [Spacers.scad, Spacers.stl]
2019-11-30 Fix issue with RTC not being formally initialised
    [Clock.cpp]
2019-12-01 Remove Wire.begin, because rtc.begin calls it again anyway
2019-12-28 Tidy leaft over intermediate files
    Add ignore rules for KiCad temporary files and rmeove those left behind.

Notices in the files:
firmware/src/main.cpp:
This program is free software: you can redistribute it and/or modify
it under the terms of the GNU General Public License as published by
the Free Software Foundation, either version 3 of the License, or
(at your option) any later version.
